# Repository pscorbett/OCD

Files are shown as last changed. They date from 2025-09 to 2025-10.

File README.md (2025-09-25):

# Over-Complicated Distortion (OCD)

This is a highly tweakable distortion pedal based around soft-clipping diodes in feedback.

## Controls
1. **Drive:** Adds gain to push the diodes into their non-linear region.
2. **Filter:** Crossmixes between Lowpass Filter and Highpass Filter. The 2nd-order Salley-key filter occurs before the clipping stage.
3. **Bias:** Adds a DC shift to the signal prior to the clipping stage. This can be used for asymmetric clipping as would occur in many tube and transistor Class-A amplifiers if they exceed their linear range.
4. **Symmetry:** Blends betweent the forward and reverse steering diodes in the feedback path. At higher gain values, the asymmetry will be diminished as the second set of (symmetric) clipping diodes is mixed in. This is done to achieve more extreme waveshaping than is possible with the resistance from the potentiometer limitng the steering current.
5. **Attenuvert:** This acts as an ouput control that affects only the clipped signal. In the CCW direction, the signal inverts.
6. **Mix:** Mixes between the dry and wet (distorted) signals. High distortion settings with low mix can simulate the crossover distortion produced by a Class B push-pull amplifier. Reversing the polarity results in a different flavor of crossover distortion.

Despite the name, this circuit has no association or deliberate simularities with other *OCD* distortion pedals.

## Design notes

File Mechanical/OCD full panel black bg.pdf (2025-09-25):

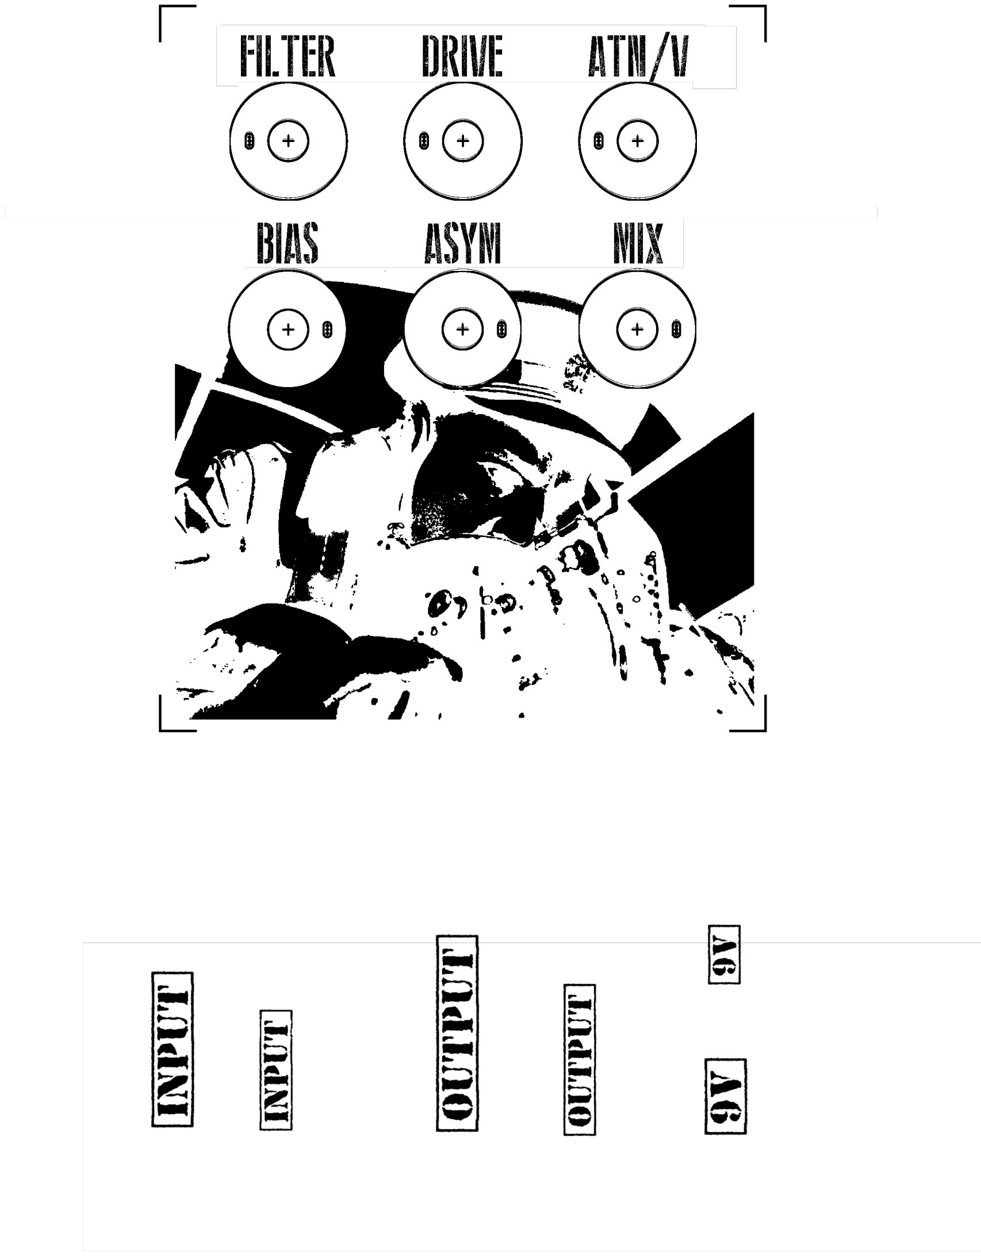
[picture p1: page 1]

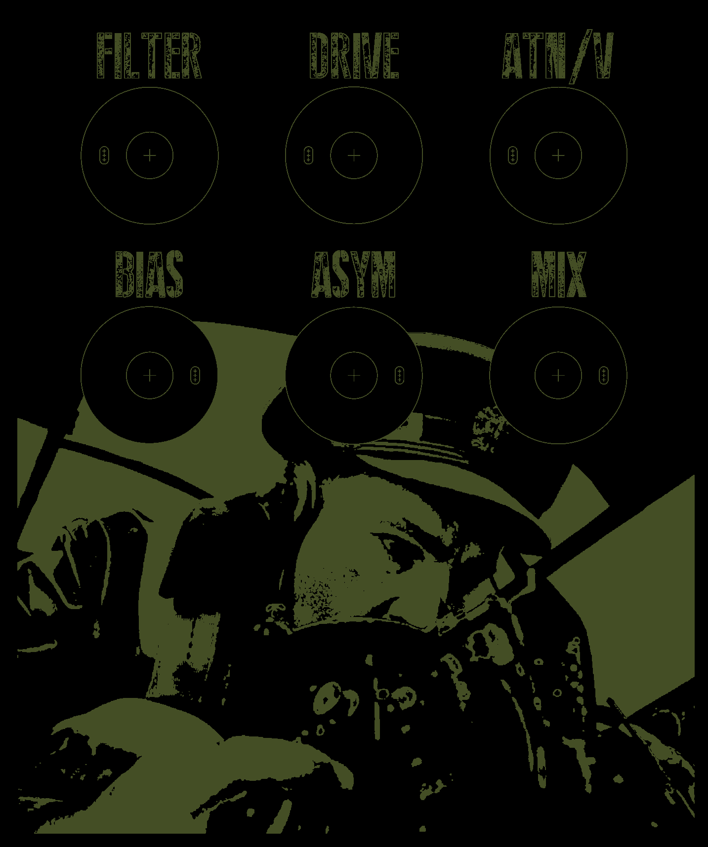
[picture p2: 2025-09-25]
Mechanical/OCD Panel Olive Drab LQ.png

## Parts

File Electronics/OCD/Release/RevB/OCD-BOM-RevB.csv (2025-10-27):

Value | Reference | Footprint | Package | Qty | DNP | Manufacturer | Part Number | SKU | Distributer
+9V Battery | BT1 | Connector_PinHeader_2.54mm:PinHeader_1x02_P2.54mm_Vertical | - | 1 |  | TAWAIN | BH9VPC | A-843 | TAYDA
22uF | C1 | Capacitor_SMD:C_0805_2012Metric |  | 1 |  | Samsung Electro-Mechanics | CL21A226MAQNNNE | C45783 | LCSC
10uF | C2,C6 | Capacitor_SMD:C_0805_2012Metric | C_0805 | 2 |  | Murata Electronics | GRM21BZ71E106KE15L | C237493 | LCSC
1uF | C3,C10 | Capacitor_SMD:C_0805_2012Metric | C_0805 | 2 |  | Samsung Electro-Mechanics | CL21B105KBFNNNE | C28323 | LCSC
10nF | C4 | Capacitor_SMD:C_0805_2012Metric | C_0805 | 1 |  | Murata Electronics | GRM2195C1H103JA01D | C97905 | LCSC
22nF | C5 | Capacitor_SMD:C_0805_2012Metric | C_0805 | 1 |  | Murata Electronics | GRM21B5C1H223JA01L | C77069 | LCSC
47pF | C7 | Capacitor_SMD:C_0805_2012Metric | C_0805 | 1 | DNP | Samsung Electro-Mechanics | CL21C470JBANNNC | C14857 | LCSC
47pF | C8 | Capacitor_SMD:C_0805_2012Metric | C_0805 | 1 |  | Samsung Electro-Mechanics | CL21C470JBANNNC | C14857 | LCSC
220pF | C9 | Capacitor_SMD:C_0805_2012Metric | C_0805 | 1 |  | Samsung Electro-Mechanics | CL21C221JBANNNC | C61747 | LCSC
100nF | C11,C12 | Capacitor_SMD:C_0805_2012Metric | C_0805 | 2 |  | Samsung Electro-Mechanics | CL21B104KCFNNNE | C28233 | LCSC
220uF | C13 | Capacitor_SMD:CP_Elec_8x10 | C_0805 | 1 |  | Nichicon | UUD1E221MNL1GS | C433299 | LCSC
1N4148WS | D2,D3,D4,D5 | PCM_Diode_SMD_AKL:D_SOD-323 | SOD-323 | 4 |  | ST(Semtech) | 1N4148WS | C57759 | LCSC
TE-CK-6.35-29B | J1 | Osprey_Footprints:TE-CK-6.35-29B | - | 1 |  | TAYDA | TE-PJ-645C | A-3575 | TAYDA
Barrel_Jack_Switch | J2 | Connector_PinHeader_2.54mm:PinHeader_1x03_P2.54mm_Vertical | - | 1 |  | WEALTH METAL | DC Power Bulkhead Jack 2.1mm | A-844 | TAYDA
PJ-645C MONO | J3 | Osprey_Footprints:PJ-644C MONO | - | 1 |  | TAYDA | PJ-645C MONO | A-6042 | TAYDA
1k | R1 | Resistor_SMD:R_0805_2012Metric | R_0805 | 1 |  | UNI-ROYAL(Uniroyal Elec) | 0805W8F1001T5E | C17513 | LCSC
100k | R2,R3,R4,R5,R8,R9,R10,R11,R32 | Resistor_SMD:R_0805_2012Metric | R_0805 | 9 |  | UNI-ROYAL(Uniroyal Elec) | 0805W8F1003T5E | C149504 | LCSC
10k | R6,R12,R13,R16,R17,R18,R19,R20,R22,R26,R28,R29,R30,R31,R33 | Resistor_SMD:R_0805_2012Metric | R_0805 | 15 |  | UNI-ROYAL(Uniroyal Elec) | 0805W8F1002T5E | C17414 | LCSC
12k | R7 | Resistor_SMD:R_0805_2012Metric | R_0805 | 1 |  | UNI-ROYAL(Uniroyal Elec) | 0805W8F1202T5E | C17444 | LCSC
47k | R14,R15 | Resistor_SMD:R_0805_2012Metric | R_0805 | 2 |  | UNI-ROYAL(Uniroyal Elec) | 0805W8F4702T5E | C17713 | LCSC
100R | R21 | Resistor_SMD:R_0805_2012Metric | R_0805 | 1 |  | UNI-ROYAL(Uniroyal Elec) | 0805W8F1000T5E | C17408 | LCSC
150k | R23,R24,R25 | Resistor_SMD:R_0805_2012Metric | R_0805 | 3 |  | UNI-ROYAL(Uniroyal Elec) | 0805W8F1503T5E | C17470 | LCSC
3.3k | R27 | Resistor_SMD:R_0805_2012Metric | R_0805 | 1 |  | UNI-ROYAL(Uniroyal Elec) | 0805W8F3301T5E | C26010 | LCSC
50k Lin | RV1 | Osprey_Footprints:RV16AF-41 | - | 1 |  | ALPHA | RV16106NO-OS15A00-B50K-060C | A-5524 | TAYDA
10k Lin | RV2 | Osprey_Footprints:RV16AF-41 | - | 1 |  | Tayda Electronics | RV16106NO-OS15A00-B10K-060C | A-5523 | TAYDA
2k Lin | RV3 | Osprey_Footprints:RV16AF-41 | - | 1 |  | Tayda Electronics | RV16AF-41-15R1-B2K | A-3921 | TAYDA
10k Lin | RV4 | Osprey_Footprints:RV16A10F-41-(L)R-XXX-3X(3) | - | 1 |  | TAYDA | RV16106GO-0S15AO0-B10K-060 | A-5680 | TAYDA
100k Lin | RV5,RV11 | Osprey_Footprints:RV16AF-41 | - | 2 |  | Tayda Electronics | RV16106NO-OS15A00-B100K-060C | A-5519 | TAYDA
SW_3PDT_x3 | SW1 | Connector_PinHeader_2.54mm:PinHeader_1x09_P2.54mm_Vertical | - | 1 |  | PIC | PBS-24-302-N2 Red/Green LED | A-1784 | TAYDA
SW_DIP_x01 | SW2 | Button_Switch_SMD:SW_DIP_SPSTx01_Slide_6.7x4.1mm_W8.61mm_P2.54mm_LowProfile | - | 1 |  | DongGuan KINGTEK Industrial Co.,LTD | DSIC01LSGET | C54948 | LCSC
TL074H | U1,U2 | Package_SO:SOIC-14_3.9x8.7mm_P1.27mm | SOIC-14 | 2 |  | Texas Instruments | TL074HIDR | C2878713 | LCSC

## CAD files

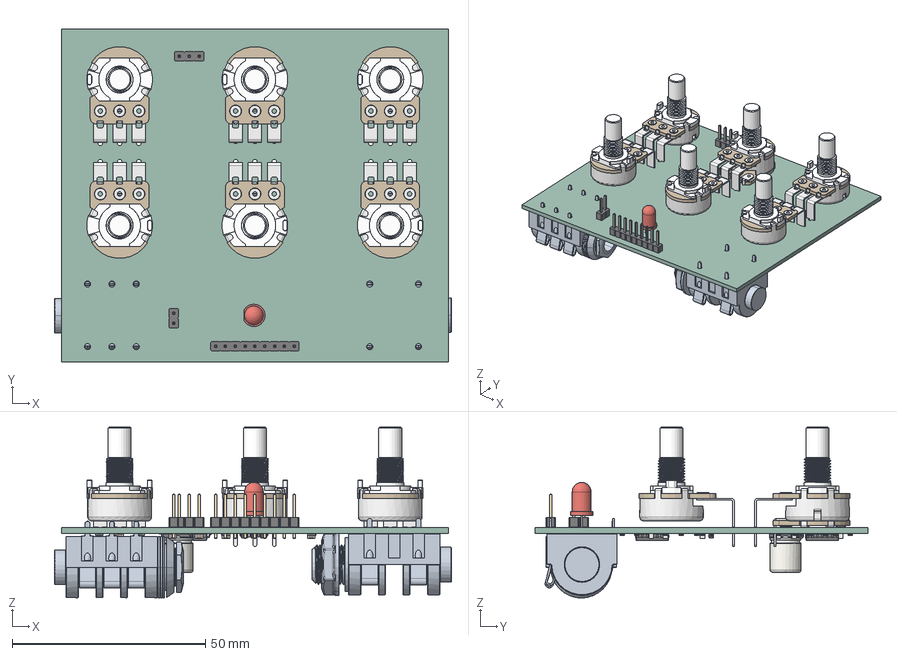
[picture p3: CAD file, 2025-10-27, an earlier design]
Electronics/OCD/Release/RevA/OCD-3D-Simple-RevA.step
102.7 x 86.0 x 44.2 mm
RV16AF-41 x 5
PinHeader_1x02_P2.54mm_Vertical
RV16A01F-41
PinHeader_1x03_P2.54mm_Vertical
PinHeader_1x09_P2.54mm_Vertical
LED_D5.0mm
C_0805_2012Metric x 12
D_SOD-323 x 4
6_3 Jack body
Nut
6_3 Jack contact_01 x 2
6_3 Jack contact_02 x 2
SOIC-14_3.9x8.7mm_P1.27mm x 2
R_0805_2012Metric x 31
CP_Elec_8x10
=>[0:1:1:2]
=>[0:1:1:6]
=>[0:1:1:9] x 3
=>[0:1:1:11]
=>[0:1:1:13]
=>[0:1:1:15] x 3
=>[0:1:1:23]
=>[0:1:1:27]
OCD_PCB

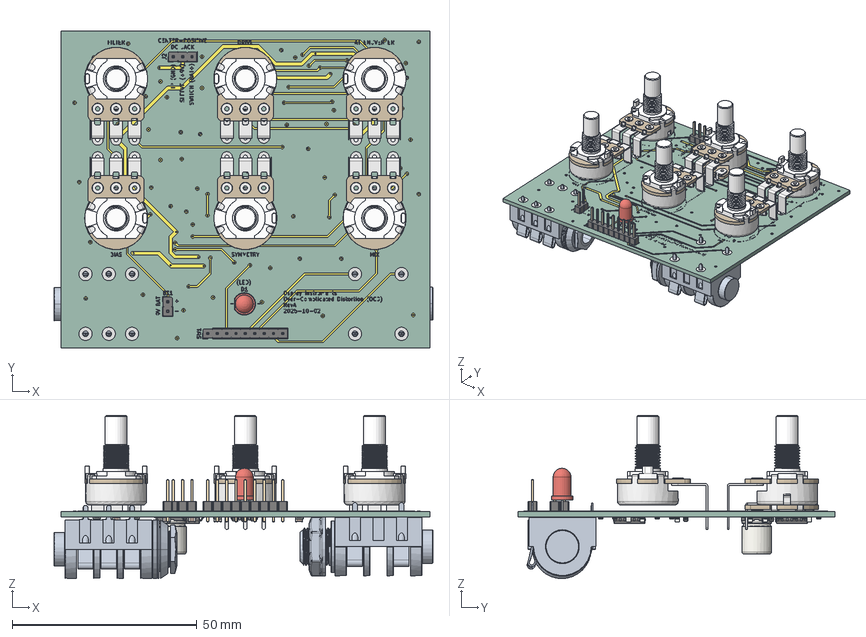
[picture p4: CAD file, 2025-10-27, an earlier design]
Electronics/OCD/Release/RevA/OCD-3D-Detailed-RevA.step
102.7 x 86.0 x 44.2 mm
RV16AF-41 x 5
PinHeader_1x02_P2.54mm_Vertical
RV16A01F-41
PinHeader_1x03_P2.54mm_Vertical
PinHeader_1x09_P2.54mm_Vertical
LED_D5.0mm
C_0805_2012Metric x 12
D_SOD-323 x 4
6_3 Jack body
Nut
6_3 Jack contact_01 x 2
6_3 Jack contact_02 x 2
SOIC-14_3.9x8.7mm_P1.27mm x 2
R_0805_2012Metric x 31
CP_Elec_8x10
=>[0:1:1:2]
=>[0:1:1:6]
=>[0:1:1:9] x 3
=>[0:1:1:11]
=>[0:1:1:13]
=>[0:1:1:15] x 3
=>[0:1:1:23]
=>[0:1:1:27]
OCD_copper
OCD_pad
OCD_via
OCD_silkscreen
OCD_PCB

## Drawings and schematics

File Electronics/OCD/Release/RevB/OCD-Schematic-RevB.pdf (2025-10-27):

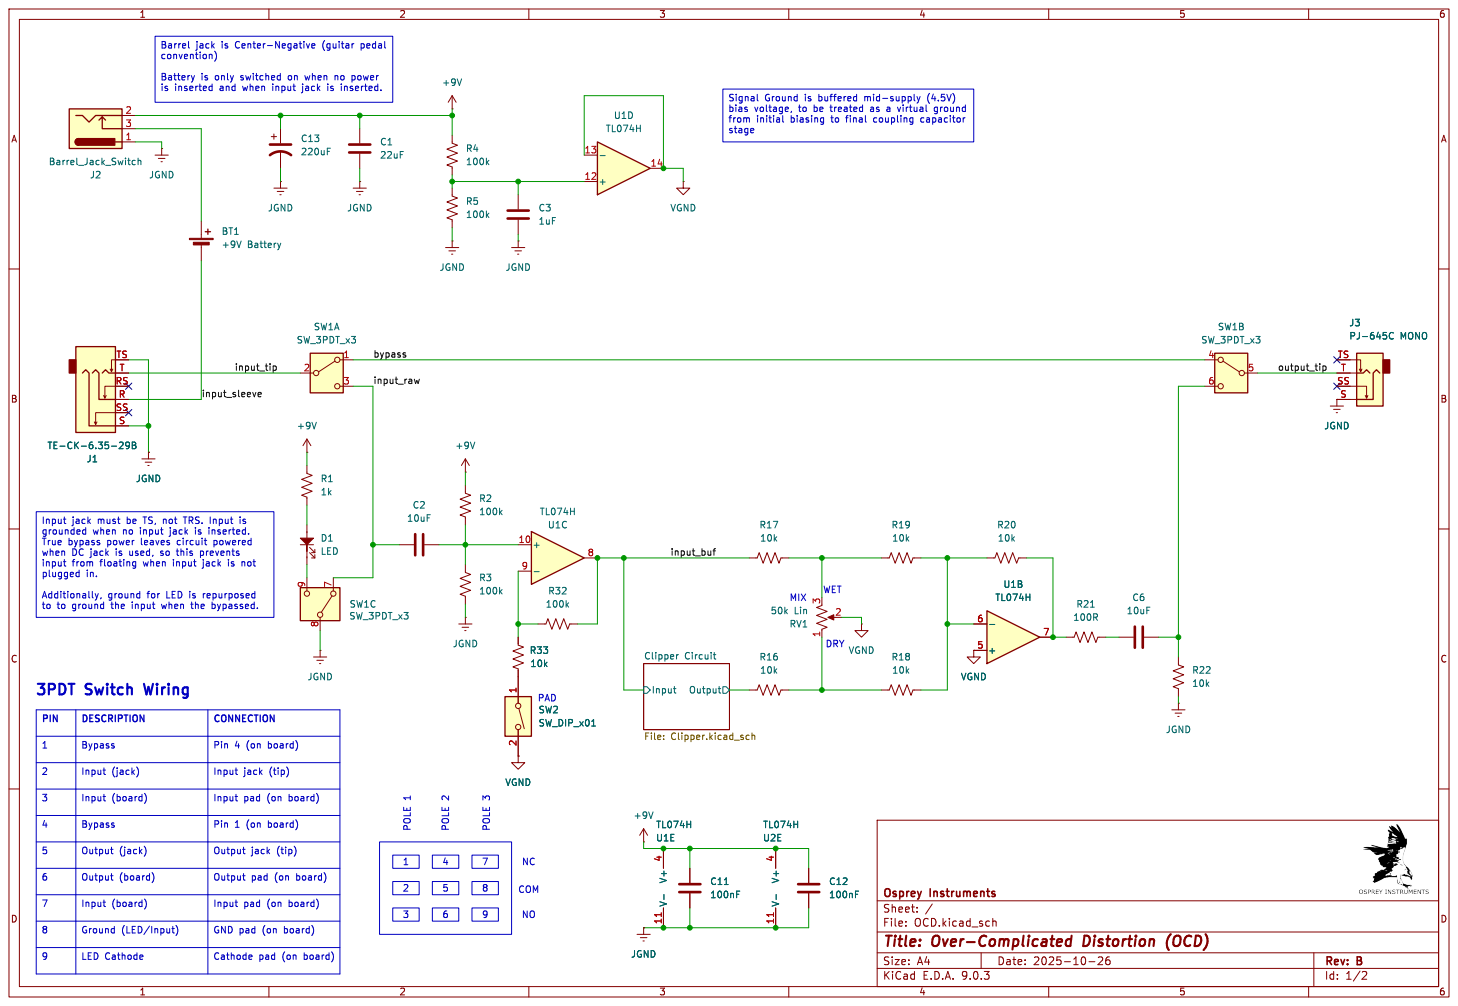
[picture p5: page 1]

Battery is only switched on when no power

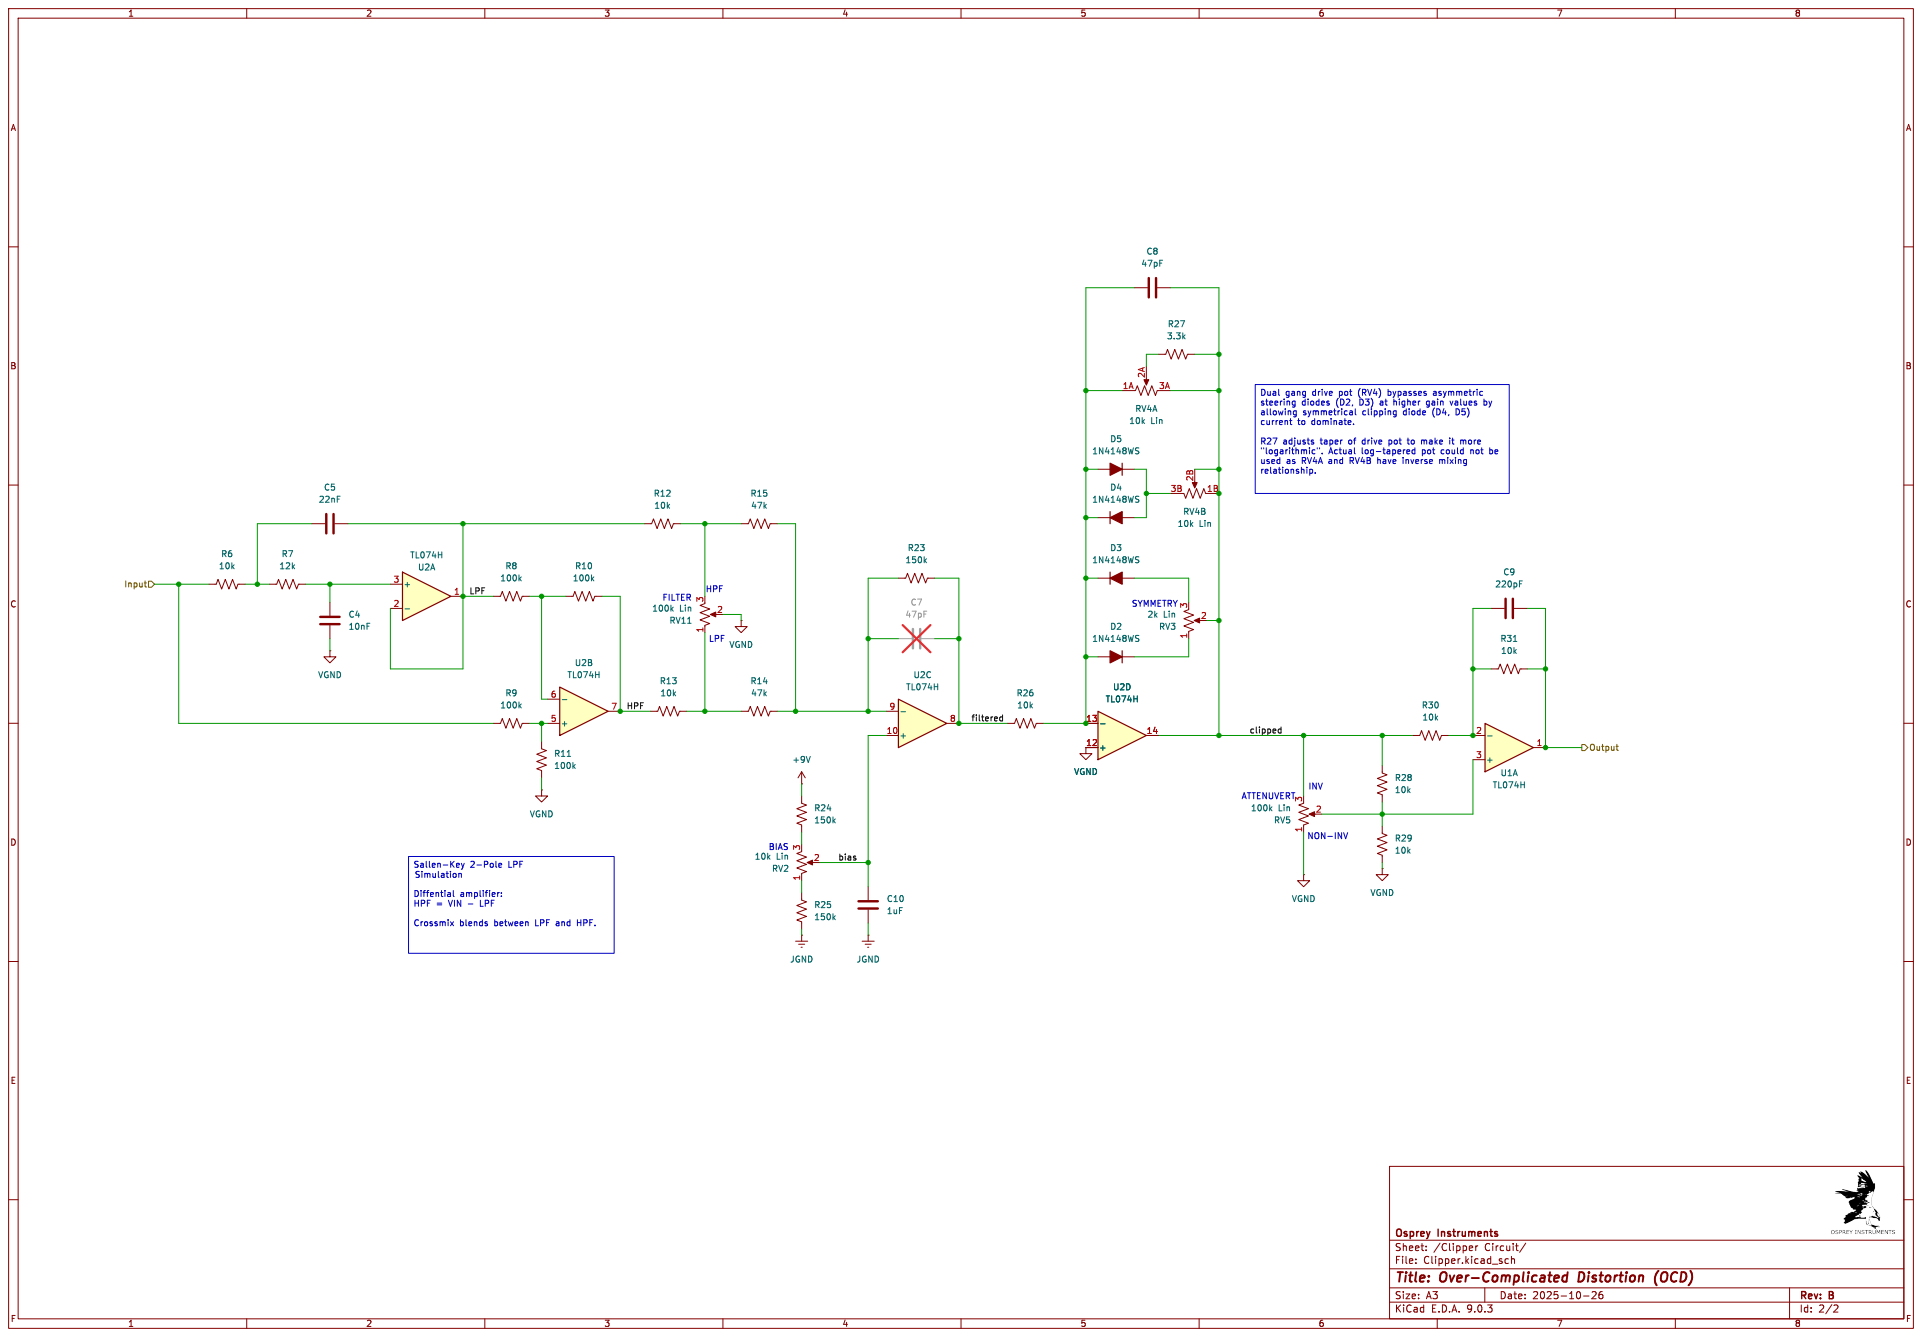
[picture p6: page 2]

Dual gang drive pot (RV4) bypasses asymmetric
relationship. ATTENUVERT

used as RV4A and RV4B have inverse mixing

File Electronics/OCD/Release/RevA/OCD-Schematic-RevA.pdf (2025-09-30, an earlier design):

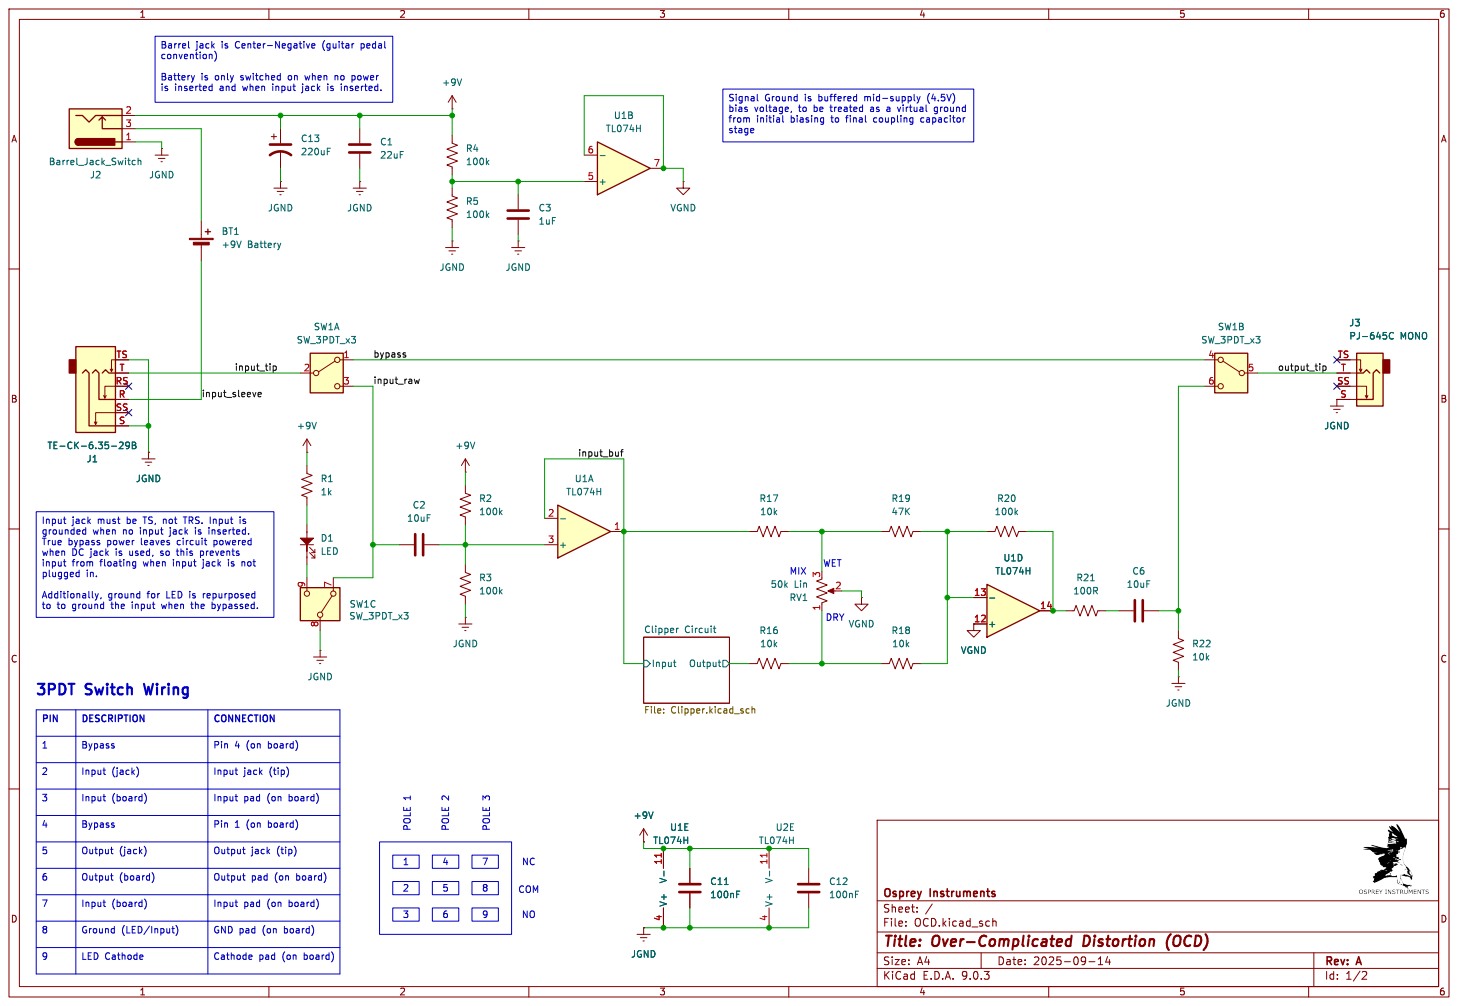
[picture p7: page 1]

Battery is only switched on when no power

to to ground the input when the bypassed.

Clipper Circuit File: Clipper.kicad_sch

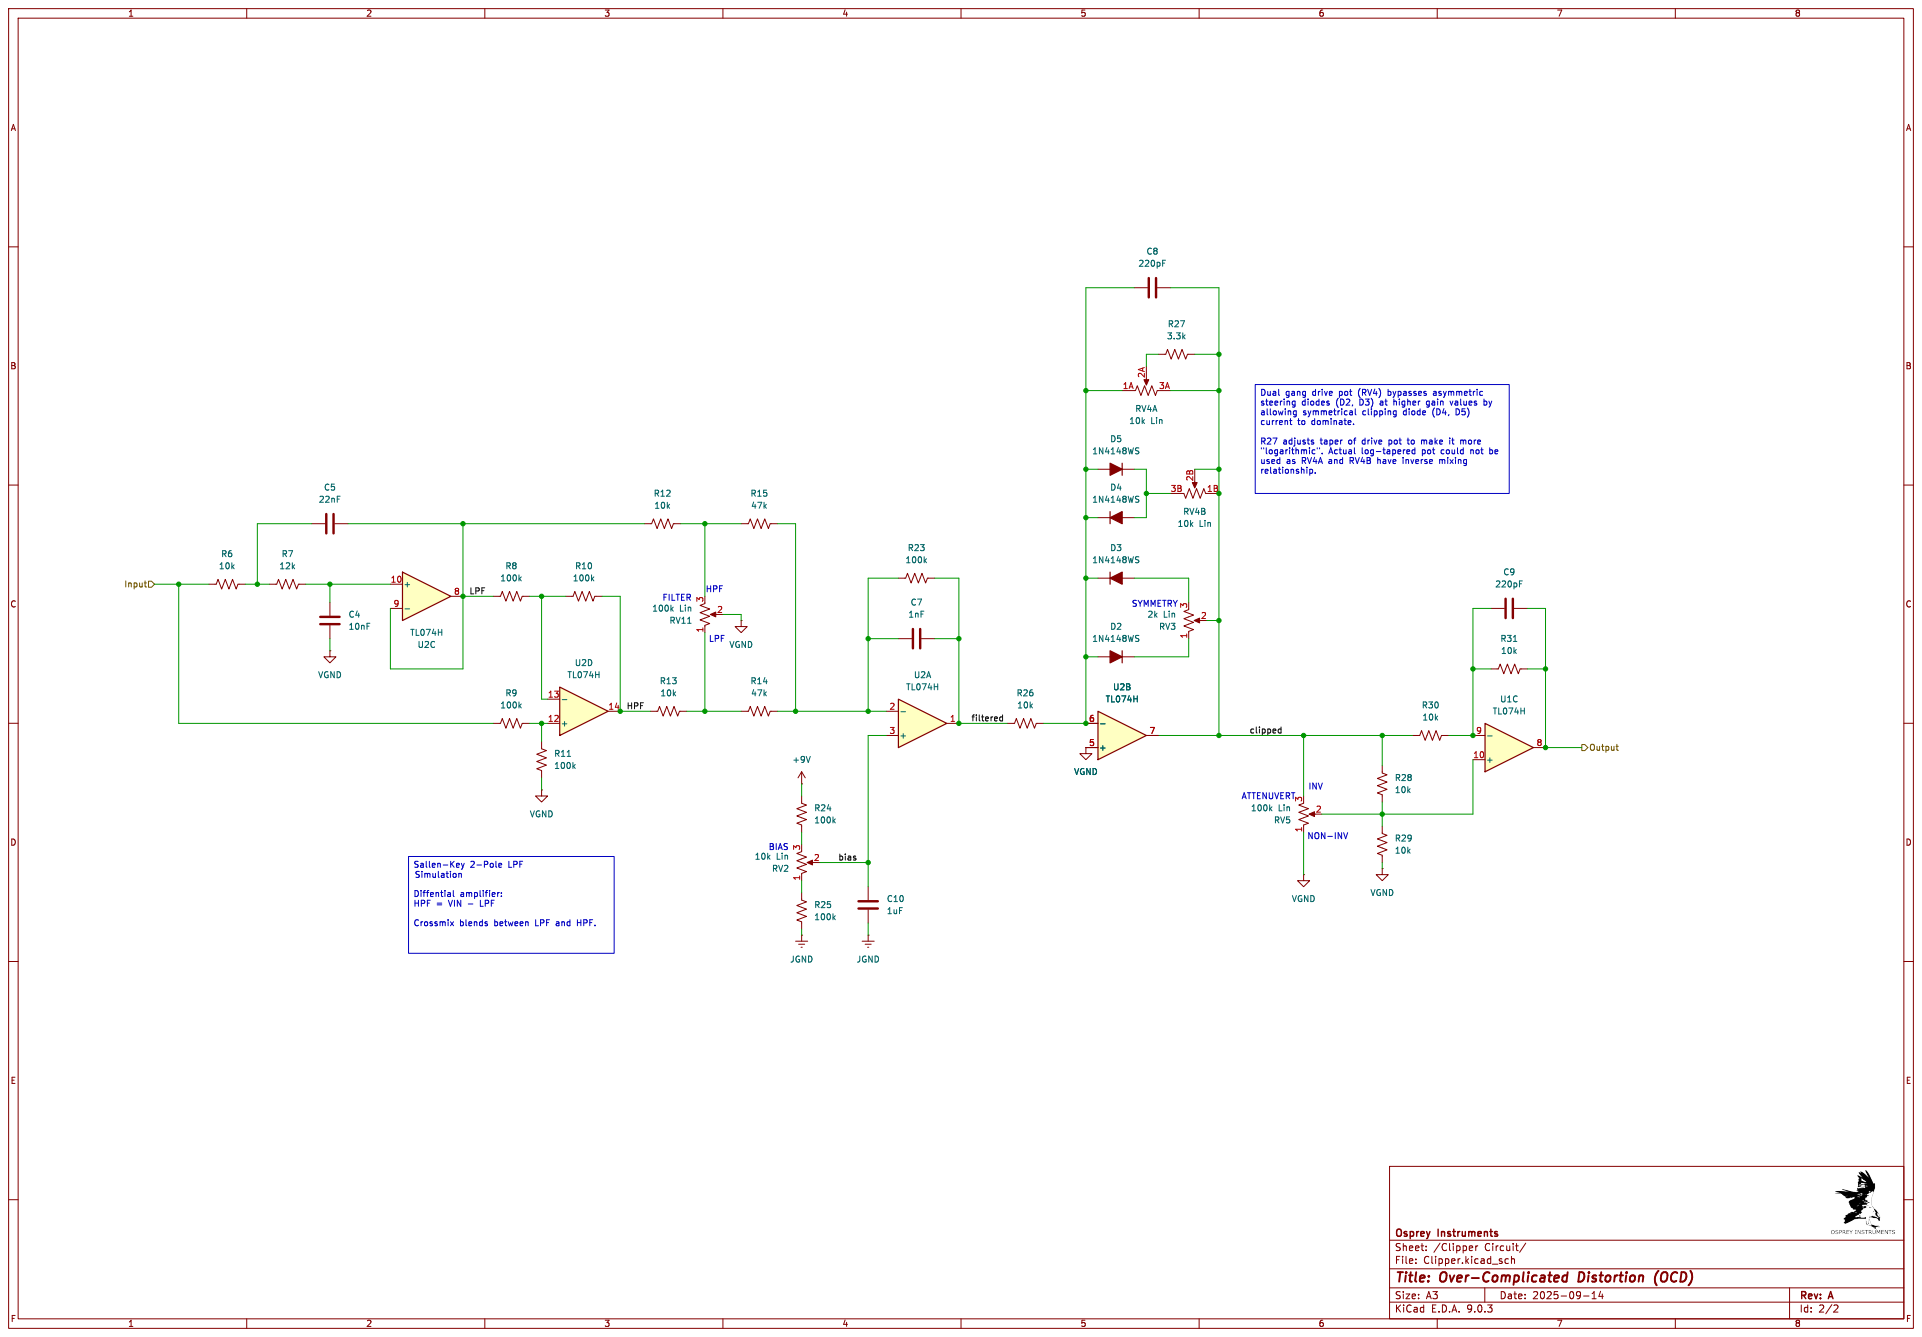
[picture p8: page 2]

Dual gang drive pot (RV4) bypasses asymmetric

used as RV4A and RV4B have inverse mixing

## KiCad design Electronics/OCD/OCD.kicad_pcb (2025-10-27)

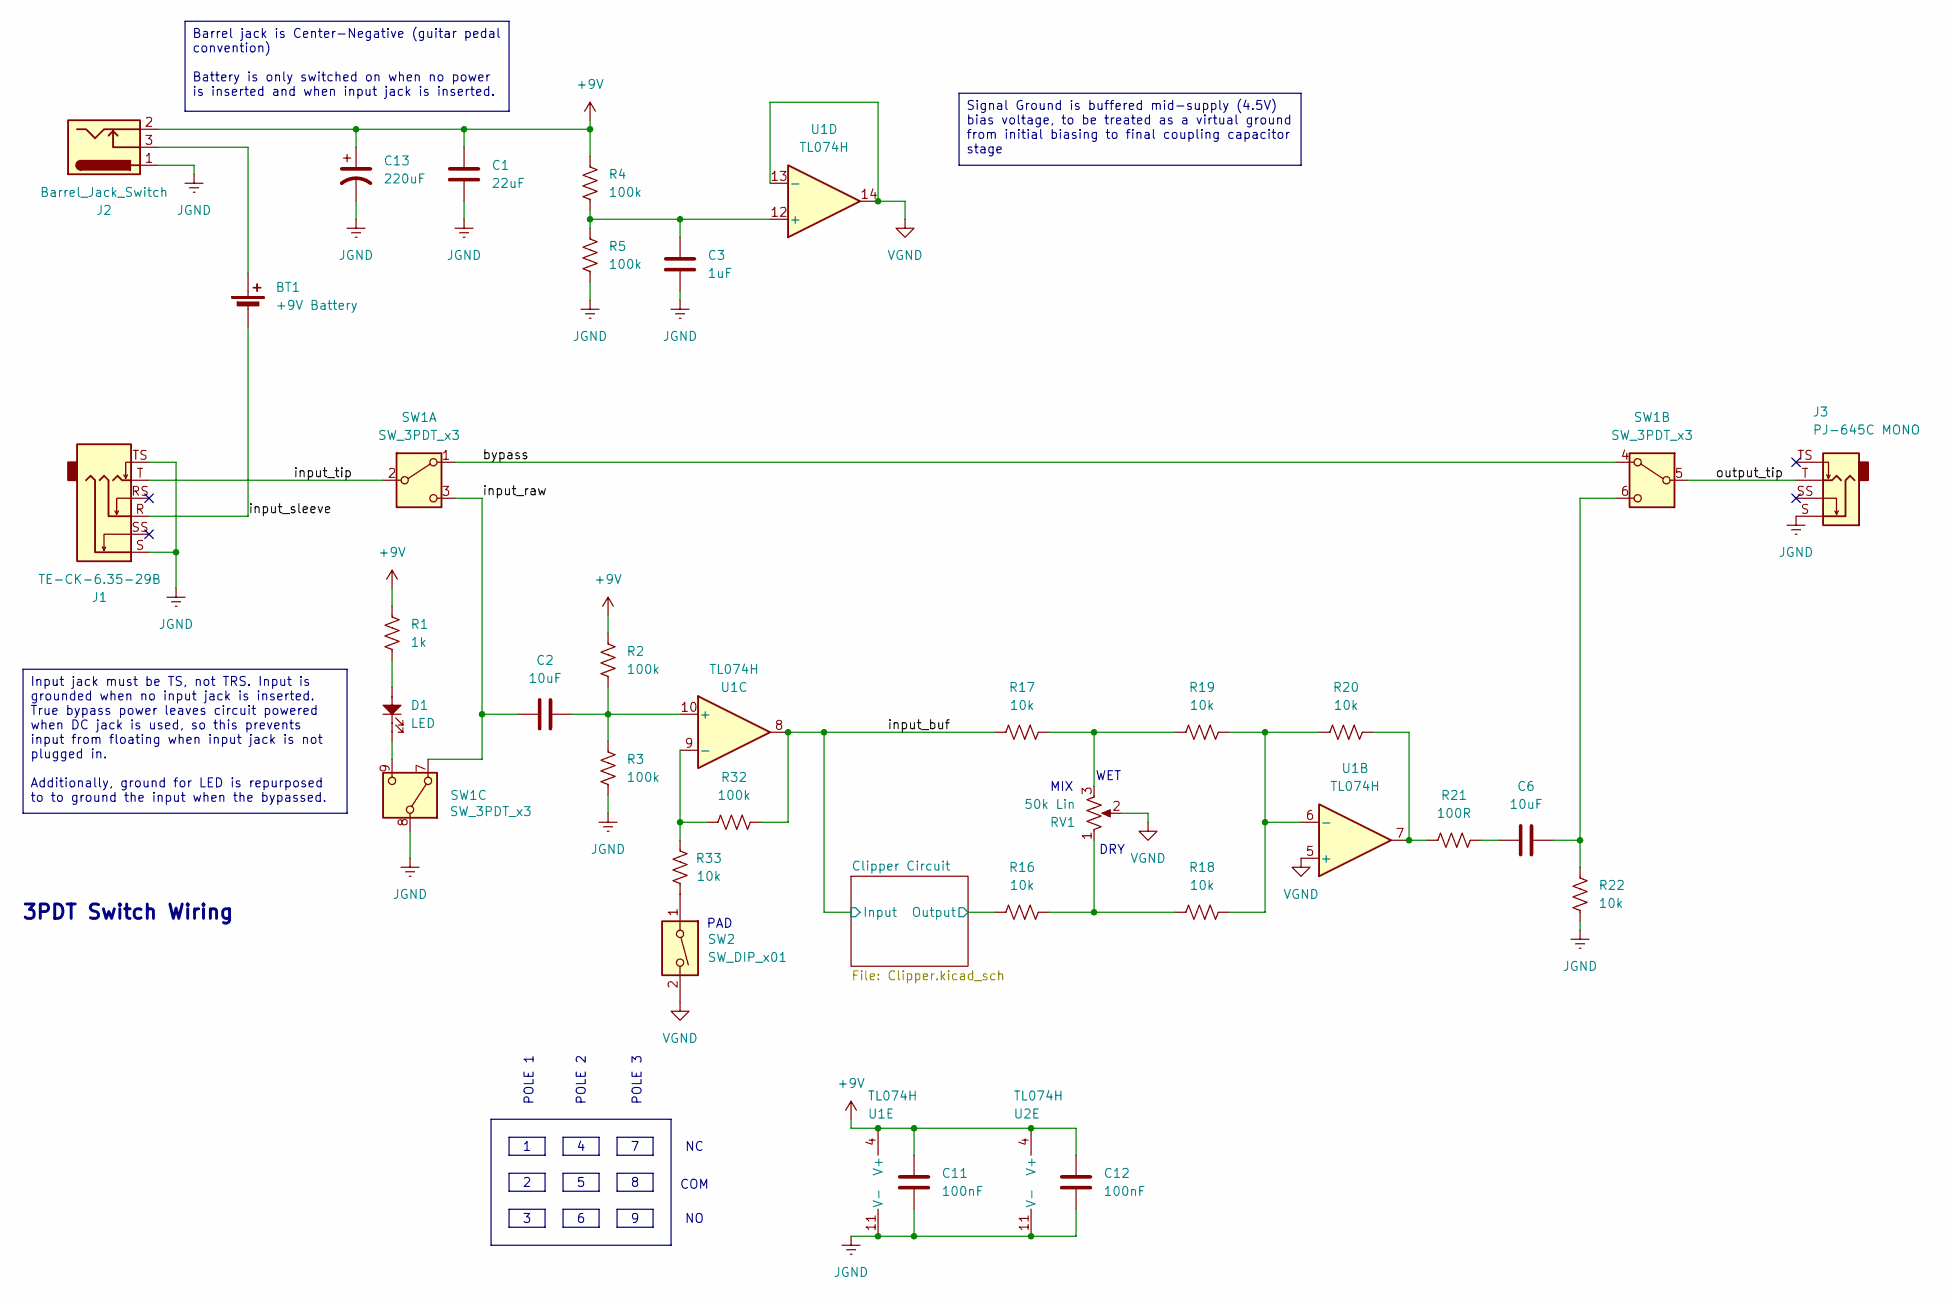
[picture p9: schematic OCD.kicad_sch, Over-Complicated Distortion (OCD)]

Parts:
BT1: +9V Battery; PinHeader_1x02_P2.54mm_Vertical; Part Number BH9VPC
C1: 22uF; C_0805_2012Metric; Part Number CL21A226MAQNNNE
C2, C6: 10uF; C_0805_2012Metric; Part Number GRM21BZ71E106KE15L
C3: 1uF; C_0805_2012Metric; Part Number CL21B105KBFNNNE
C11, C12: 100nF; C_0805_2012Metric; Part Number CL21B104KCFNNNE
C13: 220uF; CP_Elec_8x10; Part Number UUD1E221MNL1GS
D1: LED; LED_D5.0mm; Part Number PBS-24-302-N2 Red/Green LED
J1: TE-CK-6.35-29B; Part Number TE-PJ-645C
J2: Barrel_Jack_Switch; PinHeader_1x03_P2.54mm_Vertical; Part Number DC Power Bulkhead Jack 2.1mm
J3: PJ-645C MONO; PJ-644C MONO; Part Number PJ-645C MONO
R1: 1k; R_0805_2012Metric; Part Number 0805W8F1001T5E
R2, R3, R4, R5, R32: 100k; R_0805_2012Metric; Part Number 0805W8F1003T5E
R16, R17, R18, R19, R20, R22, R33: 10k; R_0805_2012Metric; Part Number 0805W8F1002T5E
R21: 100R; R_0805_2012Metric; Part Number 0805W8F1000T5E
RV1: 50k Lin; RV16AF-41; Part Number RV16106NO-OS15A00-B50K-060C
SW1: SW_3PDT_x3; PinHeader_1x09_P2.54mm_Vertical; Part Number PBS-24-302-N2 Red/Green LED
SW2: SW_DIP_x01; SW_DIP_SPSTx01_Slide_6.7x4.1mm_W8.61mm_P2.54mm_LowProfile; Part Number DSIC01LSGET
U1, U2: TL074H; SOIC-14_3.9x8.7mm_P1.27mm; Part Number TL074HIDR

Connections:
+9V: C1.1, C11.2, C12.2, C13.1, J2.2, R1.1, R2.1, R4.1, U1.4 (V+), U2.4 (V+); also elsewhere on the board
/Clipper Circuit/Output: R16.1; also elsewhere on the board
/bypass: SW1.1 (A), SW1.4 (A)
/input_buf: R17.1, R32.2, U1.8; also elsewhere on the board
/input_raw: C2.1, SW1.3 (C), SW1.7 (A)
/input_sleeve: BT1.2 (-), J1.R
/input_tip: J1.T, SW1.2 (B)
/output_tip: J3.T, SW1.5 (B)
JGND: C1.2, C3.2, C11.1, C12.1, C13.2, J1.S, J1.TS, J2.1, J3.S, R3.2, R5.2, R22.1, SW1.8 (B), U1.11 (V-), U2.11 (V-); also elsewhere on the board
unnamed: BT1.1 (+), J2.3
unnamed: C6.1, R21.2
unnamed: D1.2, R1.2
unnamed: R16.2, R18.1, RV1.1
unnamed: R17.2, R19.1, RV1.3
unnamed: R20.2, R21.1, U1.7
unnamed: R33.2, SW2.1
unnamed: C6.2, R22.2, SW1.6 (C)
unnamed: D1.1, SW1.9 (C)
unnamed: R18.2, R19.2, R20.1, U1.6 (-)
unnamed: C2.2, R2.2, R3.1, U1.10 (+)
unnamed: R32.1, R33.1, U1.9 (-)
unnamed: C3.1, R4.2, R5.1, U1.12 (+)
VGND: RV1.2, SW2.2, U1.5 (+), U1.13 (-), U1.14; also elsewhere on the board

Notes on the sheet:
PAD
POLE 1
COM
3PDT Switch Wiring
WET
DRY
MIX
POLE 2
POLE 3
Signal Ground is buffered mid-supply (4.5V) bias voltage, to be treated as a virtual ground from initial biasing to final coupling capacitor stage
Barrel jack is Center-Negative (guitar pedal convention) Battery is only switched on when no power is inserted and when input jack is inserted.
Input jack must be TS, not TRS. Input is grounded when no input jack is inserted. True bypass power leaves circuit powered when DC jack is used, so this prevents input from floating when input jack is not plugged in. Additionally, ground for LED is repurposed to to ground the input when the bypasse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

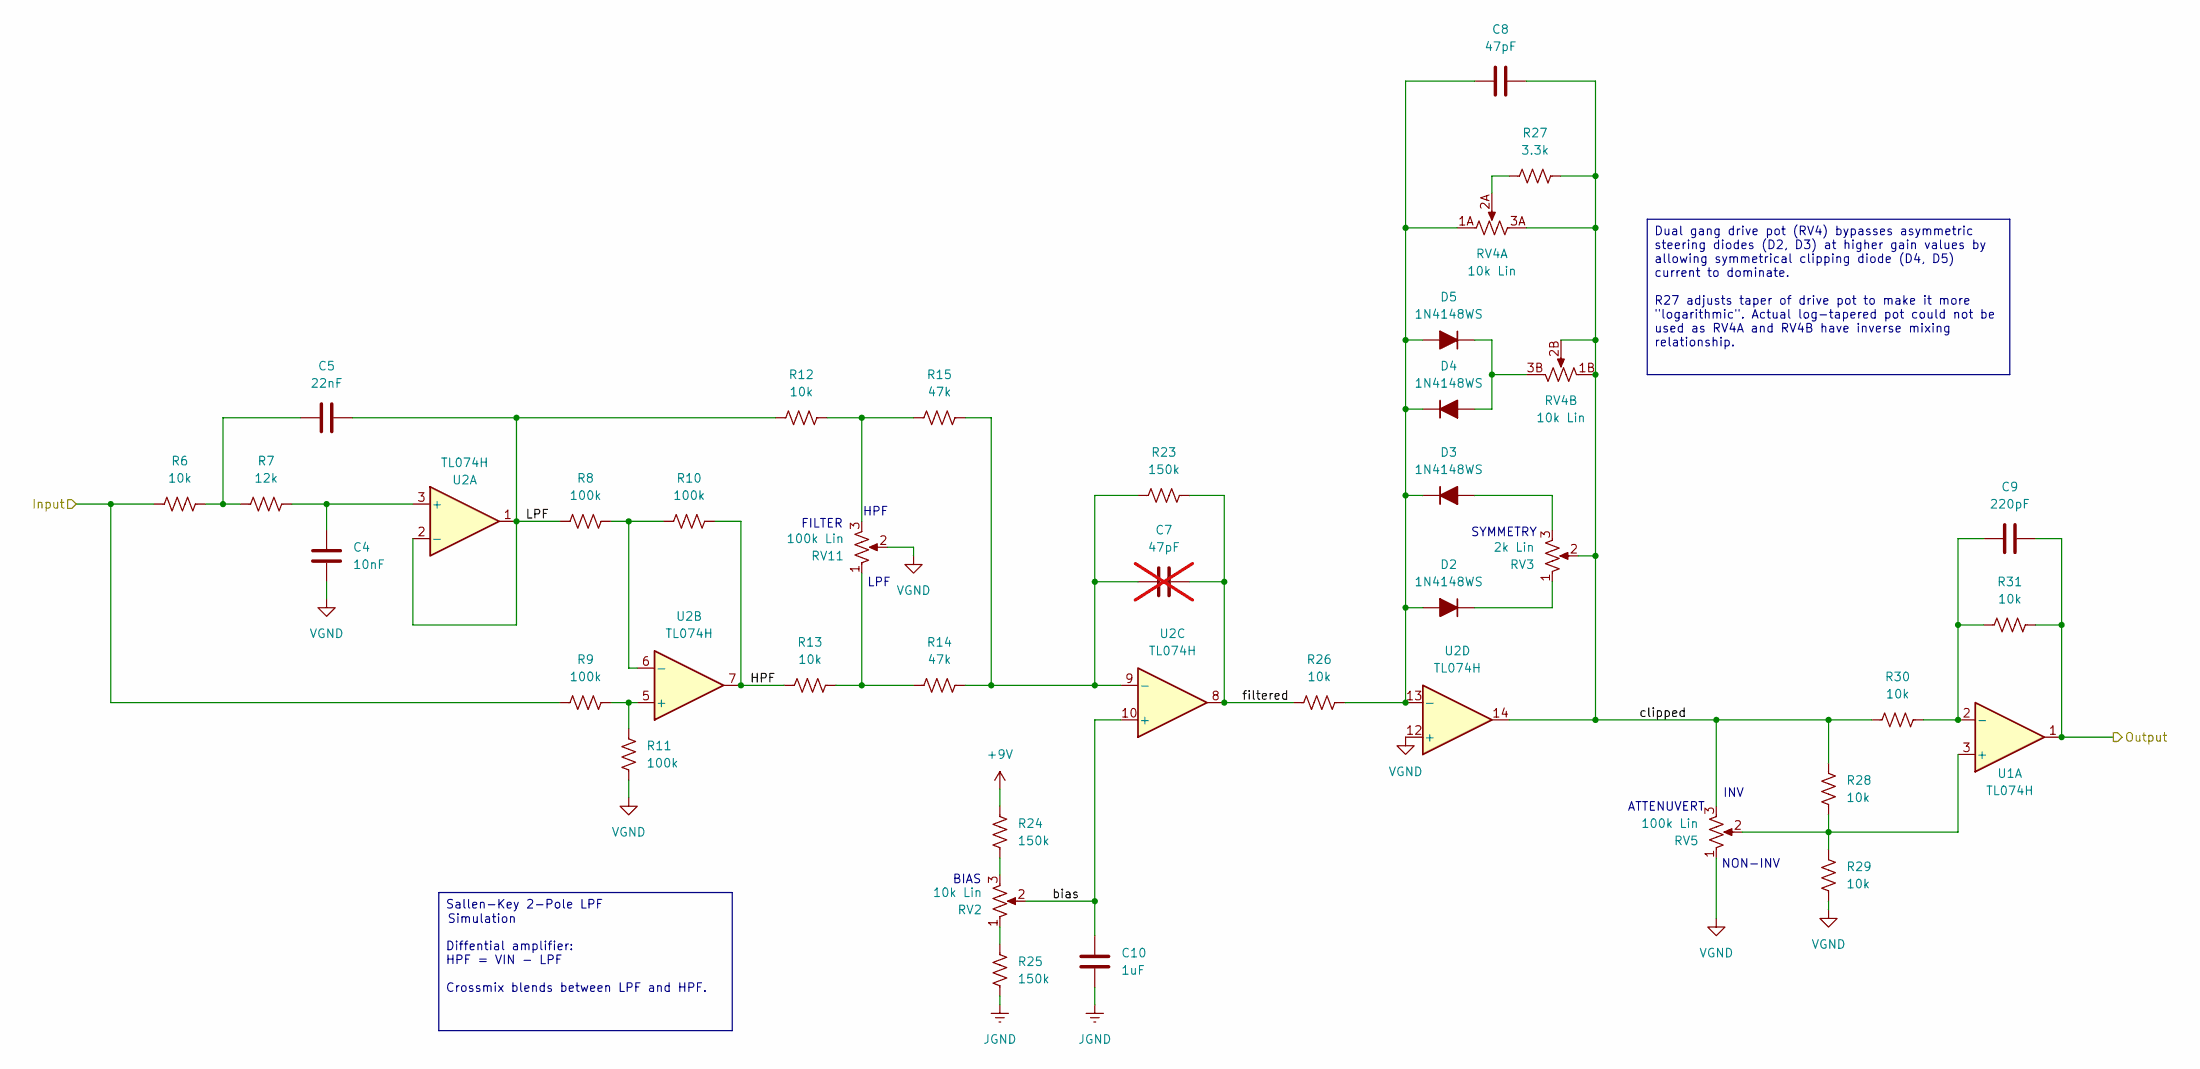
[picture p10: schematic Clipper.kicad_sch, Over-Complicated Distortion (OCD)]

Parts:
C4: 10nF; C_0805_2012Metric; Part Number GRM2195C1H103JA01D
C5: 22nF; C_0805_2012Metric; Part Number GRM21B5C1H223JA01L
C7: 47pF; C_0805_2012Metric; Part Number CL21C470JBANNNC; not fitted
C8: 47pF; C_0805_2012Metric; Part Number CL21C470JBANNNC
C9: 220pF; C_0805_2012Metric; Part Number CL21C221JBANNNC
C10: 1uF; C_0805_2012Metric; Part Number CL21B105KBFNNNE
D2, D3, D4, D5: 1N4148WS; D_SOD-323; Part Number 1N4148WS
R6, R12, R13, R26, R28, R29, R30, R31: 10k; R_0805_2012Metric; Part Number 0805W8F1002T5E
R7: 12k; R_0805_2012Metric; Part Number 0805W8F1202T5E
R8, R9, R10, R11: 100k; R_0805_2012Metric; Part Number 0805W8F1003T5E
R14, R15: 47k; R_0805_2012Metric; Part Number 0805W8F4702T5E
R23, R24, R25: 150k; R_0805_2012Metric; Part Number 0805W8F1503T5E
R27: 3.3k; R_0805_2012Metric; Part Number 0805W8F3301T5E
RV2: 10k Lin; RV16AF-41; Part Number RV16106NO-OS15A00-B10K-060C
RV3: 2k Lin; RV16AF-41; Part Number RV16AF-41-15R1-B2K
RV4: 10k Lin; RV16A10F-41-(L)R-XXX-3X(3); Part Number RV16106GO-0S15AO0-B10K-060
RV5, RV11: 100k Lin; RV16AF-41; Part Number RV16106NO-OS15A00-B100K-060C
U1, U2: TL074H; SOIC-14_3.9x8.7mm_P1.27mm; Part Number TL074HIDR

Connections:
+9V: R24.2; also elsewhere on the board
/Clipper Circuit/HPF: R10.2, R13.1, U2.7
/Clipper Circuit/LPF: C5.1, R8.1, R12.1, U2.1, U2.2 (-)
/Clipper Circuit/Output: C9.1, R31.1, U1.1; also elsewhere on the board
/Clipper Circuit/bias: C10.1, RV2.2, U2.10 (+)
/Clipper Circuit/clipped: C8.1, R27.2, R28.2, R30.2, RV3.2, RV4.1B, RV4.2B, RV4.3A, RV5.3, U2.14
/Clipper Circuit/filtered: C7.1, R23.2, R26.1, U2.8
/input_buf: R6.1, R9.1; also elsewhere on the board
JGND: C10.2, R25.1; also elsewhere on the board
unnamed: C5.2, R6.2, R7.1
unnamed: C8.2, D2.2 (A), D3.1 (K), D4.1 (K), D5.2 (A), R26.2, RV4.1A, U2.13 (-)
unnamed: D2.1 (K), RV3.1
unnamed: D3.2 (A), RV3.3
unnamed: D4.2 (A), D5.1 (K), RV4.3B
unnamed: R12.2, R15.1, RV11.3
unnamed: R13.2, R14.1, RV11.1
unnamed: R24.1, RV2.3
unnamed: R25.2, RV2.1
unnamed: R27.1, RV4.2A
unnamed: R28.1, R29.2, RV5.2, U1.3 (+)
unnamed: C9.2, R30.1, R31.2, U1.2 (-)
unnamed: C4.2, R7.2, U2.3 (+)
unnamed: R9.2, R11.2, U2.5 (+)
unnamed: R8.2, R10.1, U2.6 (-)
unnamed: C7.2, R14.2, R15.2, R23.1, U2.9 (-)
VGND: C4.1, R11.1, R29.1, RV5.1, RV11.2, U2.12 (+); also elsewhere on the board

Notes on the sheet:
ATTENUVERT
FILTER
BIAS
HPF
INV
LPF
NON-INV
SYMMETRY
Simulation
Sallen-Key 2-Pole LPF Diffential amplifier: HPF = VIN - LPF Crossmix blends between LPF and HPF.
Dual gang drive pot (RV4) bypasses asymmetric steering diodes (D2, D3) at higher gain values by allowing symmetrical clipping diode (D4, D5) current to dominate. R27 adjusts taper of drive pot to make it more "logarithmic". Actual log-tapered pot could not be used as RV4A and RV4B have inverse mixi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

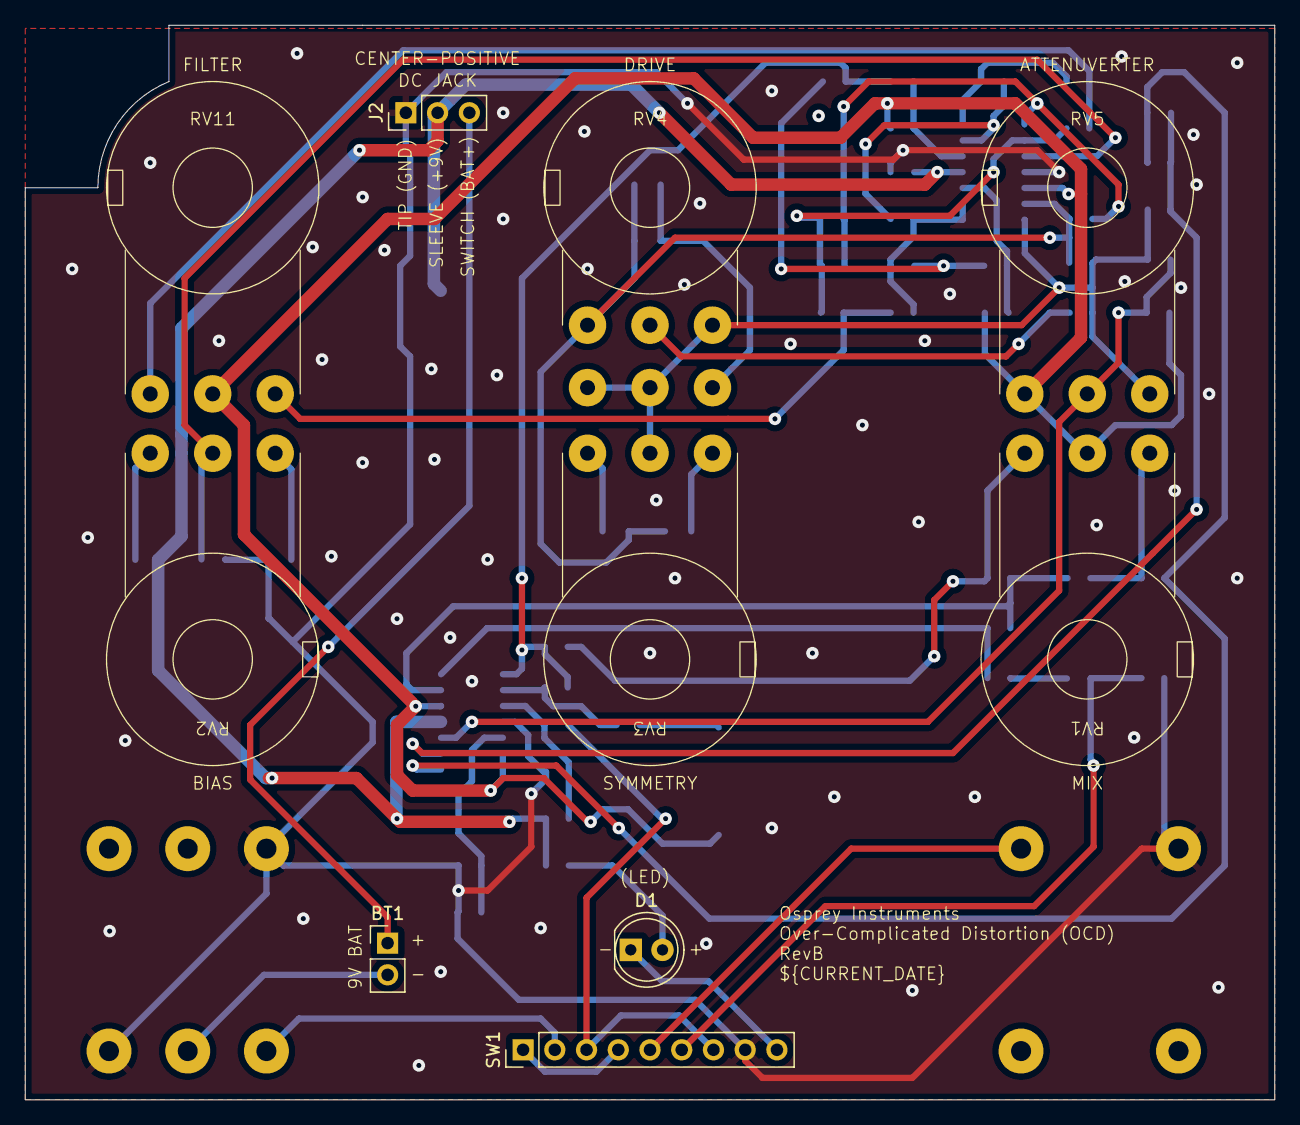
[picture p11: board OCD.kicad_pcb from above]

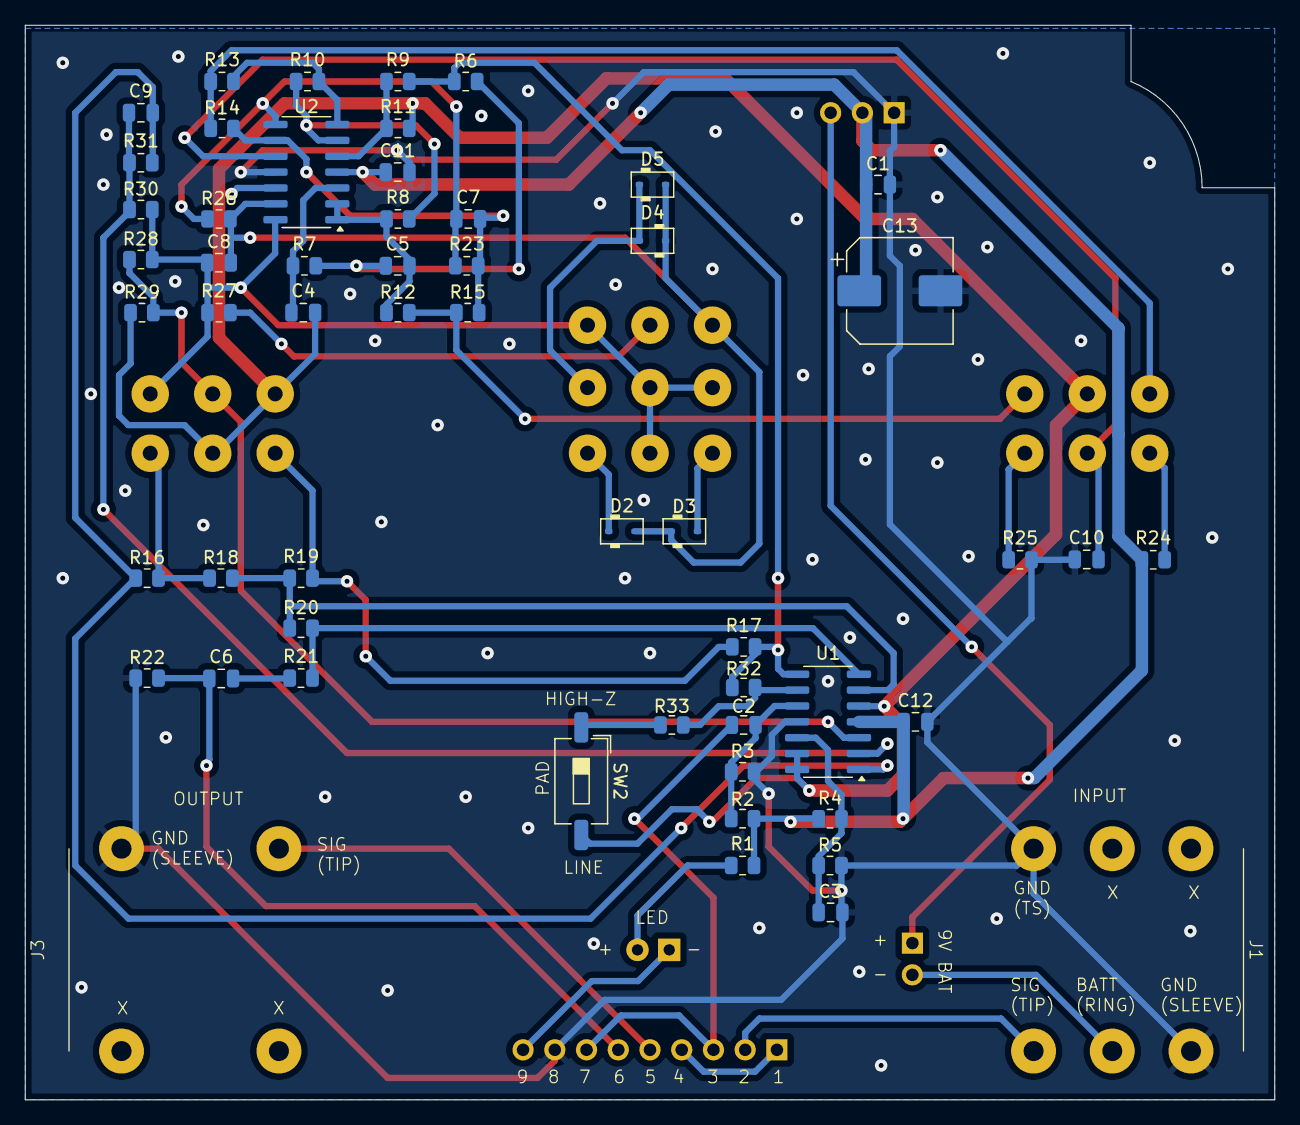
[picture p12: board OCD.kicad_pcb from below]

Board: 2 copper layers, 100.0 x 86.0 mm, 65 parts (55 on the bottom side), 44 nets.

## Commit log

2025-09-25 silkscreen pdf and schematic update to center-negative
    [Clipper.kicad_sch, OCD.kicad_pcb, OCD.kicad_sch]
2025-09-30 RevA release
    [Clipper.kicad_sch, OCD-BOM-JLC-RevA.csv, OCD-BOM-TH-RevA.csv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]
2025-10-27 RevB release. Corrected opamp orientation, added pad switch
    [Clipper.kicad_sch, OCD-3D-Detailed-RevA.step, OCD-3D-Simple-RevA.step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]
